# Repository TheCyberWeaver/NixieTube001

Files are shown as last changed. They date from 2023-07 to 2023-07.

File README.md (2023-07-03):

# NixieTube001
# A DIY Project

EL PSY CONGROO

# Including:

python program with GUI

Arduino program

PCB files

3D printing Solidworks files

# Finished Product




# Software





# Contacts

if you do not understand any part of this project, you're welcome to contact thomas.luqiyu@outlook.com
English, German and Chinese are supported (^_^)

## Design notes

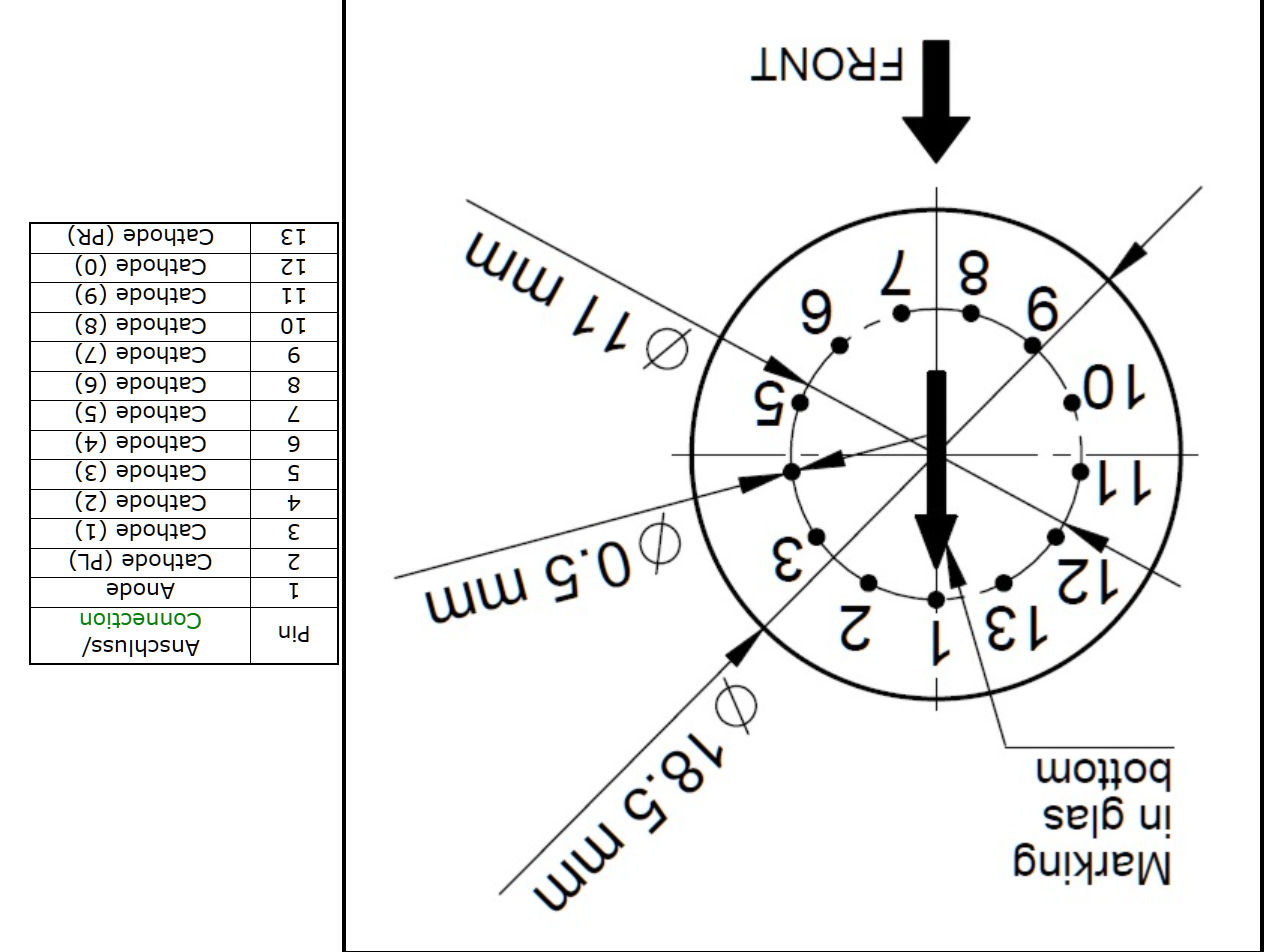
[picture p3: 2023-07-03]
Documents/Screenshot 2023-05-19 155955.png

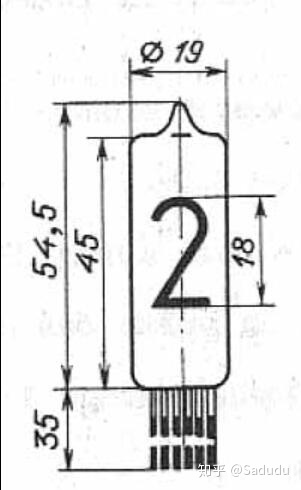
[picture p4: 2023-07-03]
Documents/v2-3904997cc60bc72c79d3f1d0ab6cf48d_1440w.jpg

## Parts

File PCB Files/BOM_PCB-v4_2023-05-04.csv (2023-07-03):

ID | Name | Designator | Footprint | Quantity | Manufacturer Part | Manufacturer | Supplier | Supplier Part | Price | Pins
1 | 22k | R1,R2,R3,R4,R5,R6,R7,R8 | R0603 | 8 |  |  |  |  |  | 2
2 | K155ID1/SN74141 | U14,U2,U3,U5,U6,U9,U10,U12,U8 | DIP16 | 9 |  |  |  |  |  | 16
3 | WIRELESS-BLUETOOTH-HC-05 | 1 | WIRELESS-BLUETOOTH-HC-05 | 1 |  |  |  |  |  | 6
4 | IN-14 | N1,N2,N3,N4,N5,N6,N7,N8 | IN-14 | 8 |  |  |  |  |  | 13
5 | SN74HC595N | U4,U7,U11,U16 | DIP-16_L19.8-W6.5-P2.54-LS7.6-BL | 4 | SN74HC595N | TI(德州仪器) | LCSC | C78711 | 0.037 | 16
6 | DS3231 PI | U15 | DS3231 PI | 1 |  |  |  |  |  | 5
7 | ARDUINO_NANO | U1 | COMM-TH_ARDUINO_NANO | 1 | ARDUINO_NANO | null | LCSC | C9900017879 |  | 30
8 | HDR-M-2.54_1x4 | J1 | HDR-M-2.54_1X4 | 1 |  |  | LCSC | C124378 | 0.007 | 4

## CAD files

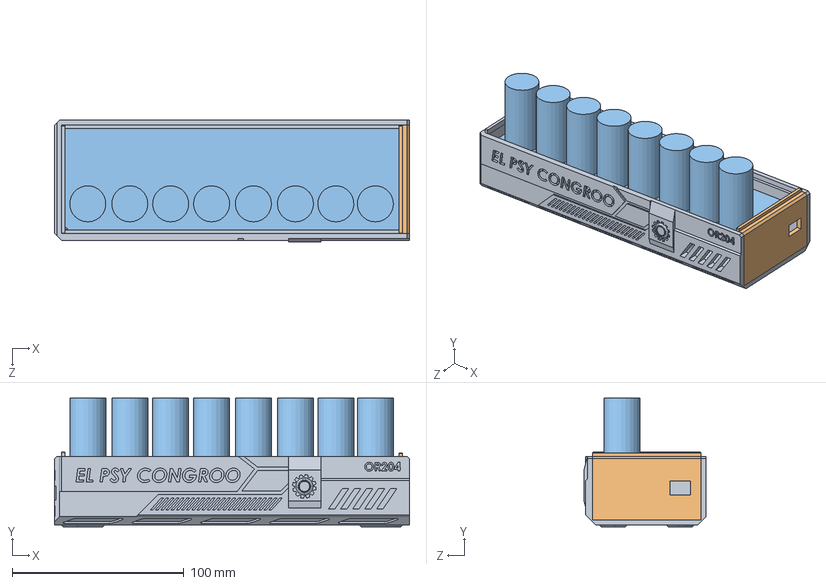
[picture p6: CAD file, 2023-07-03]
Nixie Tube 3D Files/Assem1.SLDASM
206.5 x 74.8 x 71.0 mm
PCB

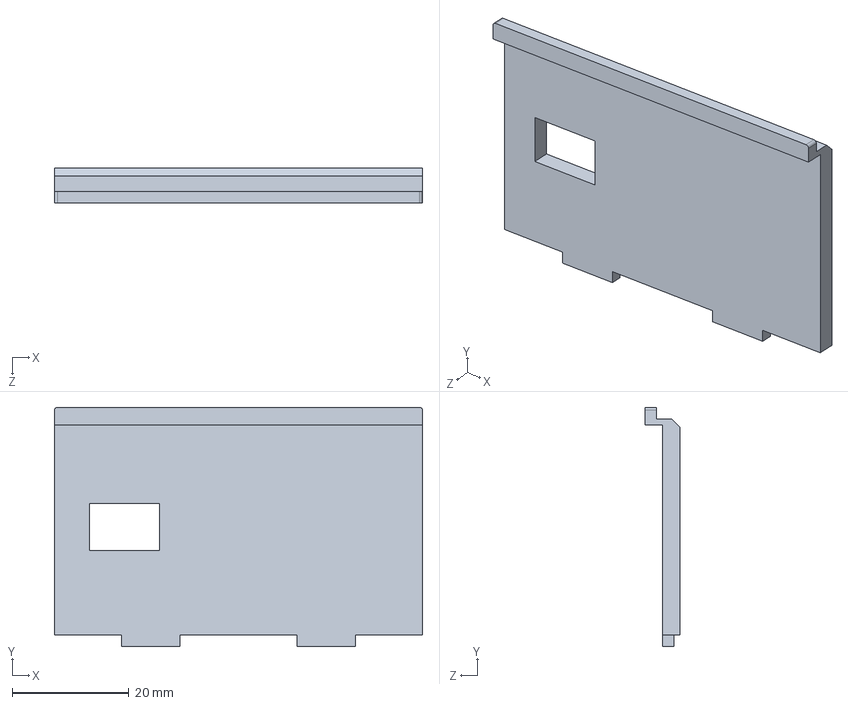
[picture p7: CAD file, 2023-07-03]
Nixie Tube 3D Files/Part2.SLDPRT
63.0 x 41.0 x 6.00 mm

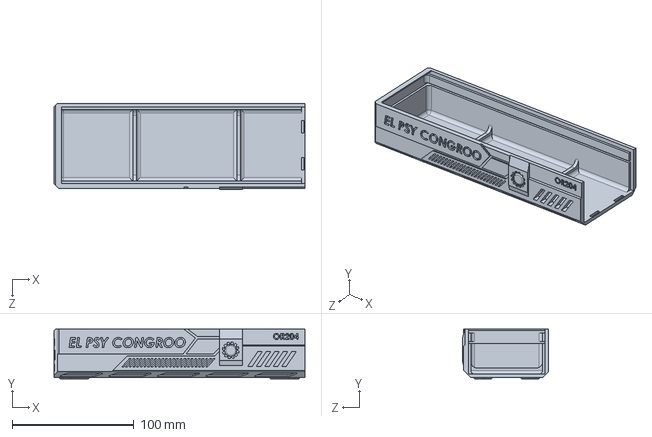
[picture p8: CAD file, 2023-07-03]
Nixie Tube 3D Files/Part1.SLDPRT
206.5 x 41.0 x 71.0 mm

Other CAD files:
Nixie Tube 3D Files/Drawing1.dwg

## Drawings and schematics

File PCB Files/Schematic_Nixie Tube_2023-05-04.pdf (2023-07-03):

A | A
B | B

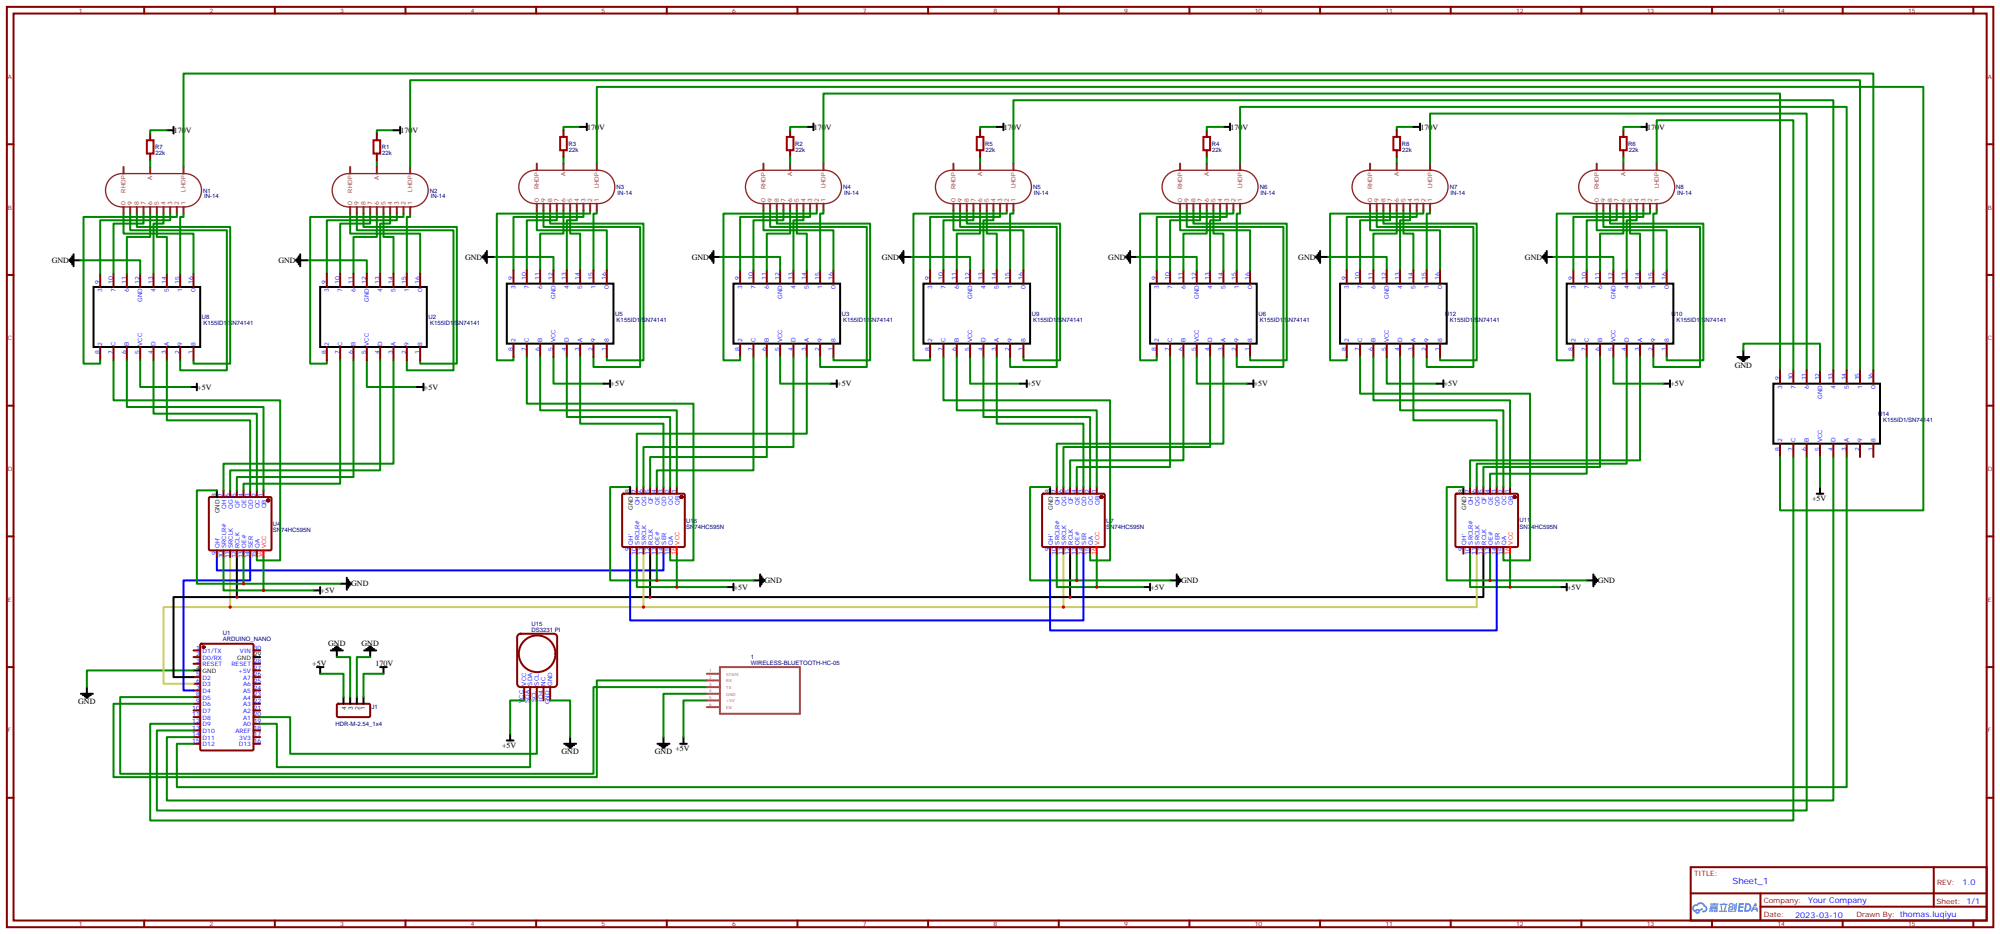
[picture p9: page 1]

GND GND NC IO4 SCL SCL SDA SDA VCC VCC

Drawn By: thomas.luqiyu

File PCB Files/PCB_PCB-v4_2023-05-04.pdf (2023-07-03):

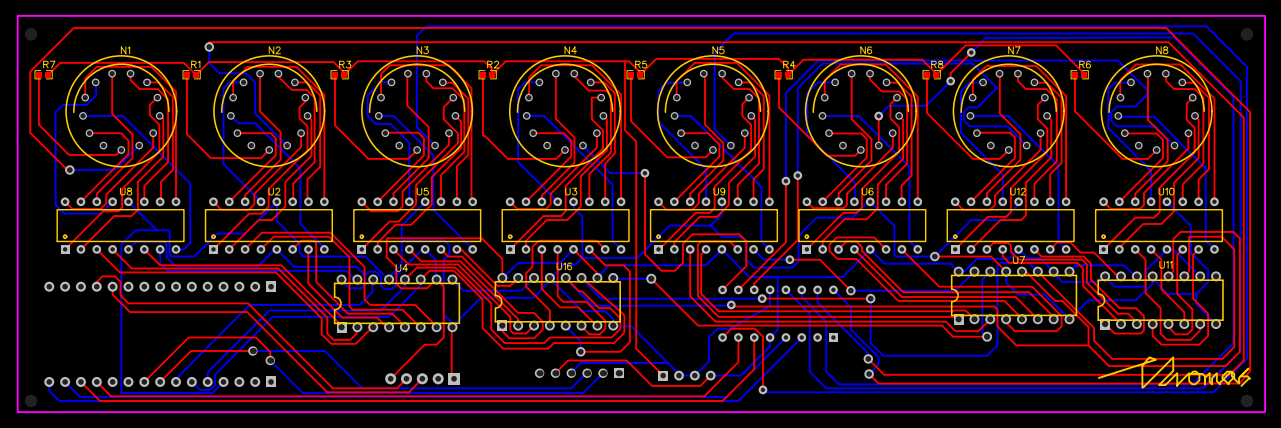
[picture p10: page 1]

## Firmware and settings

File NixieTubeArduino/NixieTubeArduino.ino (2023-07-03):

#include <SoftwareSerial.h>
#include <DS3231.h>
//global

#define dotA 12
#define dotB 10
#define dotC 9
#define dotD 11

#define SR_latchPIN 2
#define SR_clockPIN 3
#define SR_dataPIN 4

bool stopwatchPauseFlag = 1;
bool timerPauseFlag = 1;
uint8_t MODE = 2;
uint8_t timeMODE = 0;
String number = "";
Time stopwatchCurrentTime, timeALLZero, timerCurrentTime, timerResetTime;
uint8_t stopwatchMilli;

uint8_t timeOffset = 3;
int timeOffsetMicro = 603;

//initialization
SoftwareSerial Bluetooth(5, 6);
String inputString;

DS3231 rtc(A0, A1);


//String EXCEPTIONS = "";
bool DecimalPointToPins[9][4]{ { 1, 1, 1, 0 },  //the map between the 4 controlling pins and the LP pin of the nixie tube.
                               { 0, 1, 1, 0 },
                               { 1, 0, 1, 0 },
                               { 0, 0, 1, 0 },
                               { 1, 1, 0, 0 },
                               { 0, 1, 0, 0 },
                               { 1, 0, 0, 0 },
                               { 0, 0, 0, 0 },
                               { 1, 1, 1, 1 } };

uint8_t DigitsToPins[11]{ 0x8, 0x0, 0xC, 0x4, 0xB, 0x3, 0x9, 0x1, 0xA, 0x2, 0xF };  //the map between the output of shift registers and the output of  4 bits decoders. 0xF represents no output!!!



/*
  given a string of 8 digits number/float,
  check if the number/float is valid, if not, try to make it valid.
  If it fails to make it valid, than return false.
*/
bool isNumberValid(String& num) {
  if (num.length() > 8) {
    //EXCEPTIONS = "[Failed]: False digits length";
    return false;
  }
  int countofDecimalPoints = 0;
  for (int i = 0; i < num.length(); ++i) {
    if (num[i] == '.') countofDecimalPoints++;
    if (num[i] == '.' && countofDecimalPoints > 1) num[i] = '0';
    if (num[i] < 48 && num[i] != 46 || num[i] > 57) {
      //EXCEPTIONS = "[Failed]: Found unsupported characters";
      return false;
    }
  }
  if (countofDecimalPoints > 1) {
    //EXCEPTIONS = "[Warning]: change extra decimal points to 0";
  }

  return true;
}
/*
  given the index of the nixie tube,
  light up the nixie tube with a decimal point.
  !!!This function could still show the decimal point while the nixie tube is showing a digit!!!
*/
void showDecimalPoint(uint8_t index = -1) {
  if (index == -1) {
    digitalWrite(dotA, DecimalPointToPins[8][0]);
    digitalWrite(dotB, DecimalPointToPins[8][1]);
    digitalWrite(dotC, DecimalPointToPins[8][2]);
    digitalWrite(dotD, DecimalPointToPins[8][3]);
  } else {
    digitalWrite(dotA, DecimalPointToPins[index][0]);
    digitalWrite(dotB, DecimalPointToPins[index][1]);
    digitalWrite(dotC, DecimalPointToPins[index][2]);
    digitalWrite(dotD, DecimalPointToPins[index][3]);
  }
  return;
}

/*
  given the an array of 0-9 digits, 10 represents no output,
  output all 8 digits to the nixie tubes in the order from left to right.
*/
void NumberArrayToScreen(uint8_t outputDigits[8]) {
  digitalWrite(SR_latchPIN, LOW);
  //using shift register
  for (uint8_t i = 0; i < 4; ++i) {
    int tmp = (DigitsToPins[outputDigits[i * 2]] << 4) + DigitsToPins[outputDigits[i * 2 + 1]];
    shiftOut(SR_dataPIN, SR_clockPIN, MSBFIRST, tmp);
  }
  digitalWrite(SR_latchPIN, HIGH);
  return;
}
/*
  set the timer to the given string
*/
Time stringToTime(String str) {
  Time timer;

  timer.year = 2000 + str.substring(0, 2).toInt();
  timer.mon = str.substring(2, 4).toInt();
  timer.date = str.substring(4, 6).toInt();

  timer.hour = str.substring(6, 8).toInt();
  timer.min = str.substring(8, 10).toInt();
  timer.sec = str.substring(10, 12).toInt();

  return timer;
}

/*
  add time or minue time
*/
void updateCurrentTime(Time& timer, int addnum) {

  timer.sec += addnum;
  if (addnum < 0) {
    if (timer.sec == 255) {  //since time->sec is a uint8_t, it can only represent 0-255. if we minus one when it is zero, it will become 255.
      timer.sec = 59;
      timer.min -= 1;
      if (timer.min == 255) {  //same theory (^-^)
        timer.min = 59;
        timer.hour -= 1;
      }
    }
  }

  if (addnum > 0) {
    timer.min += timer.sec / 60;
    timer.sec = timer.sec % 60;

    timer.hour += timer.min / 60;
    timer.min = timer.min % 60;

    timer.date += timer.hour / 24;
    timer.hour = timer.hour % 24;
  }
}
/*
  given the left number, the index of decimal point and the right number,
  ouput an integer or a float to the nixie tubes.
  Both numbers are right aligned.
*/
void outputNumber(long wholeNumberPart, int decimalPointIndex = -1, long decimalPart = -1) {
  uint8_t outputDigits[8] = { 0 };
  if (decimalPointIndex == -1) {
    //Do not show decimal point
    showDecimalPoint(-1);

    //seperate each digits into an array
    for (int i = 0; i < 8; ++i) {
      if (wholeNumberPart != 0) {
        outputDigits[7 - i] = wholeNumberPart % 10;  //save each digits into the array in the order from left to right
        wholeNumberPart /= 10;
      }
    }
  } else {
    //show decimal point at selected location
    showDecimalPoint(decimalPointIndex);

    outputDigits[decimalPointIndex] = 10;
    for (int i = 0; i < 8; ++i) {
      if (wholeNumberPart != 0) {
        outputDigits[decimalPointIndex - i - 1] = wholeNumberPart % 10;  //save each digits into the array in the order from left to right
        wholeNumberPart /= 10;
      }
      if (decimalPart != 0) {
        outputDigits[7 - i] = decimalPart % 10;  //save each digits into the array in the order from left to right
        decimalPart /= 10;
      }
    }
  }
  NumberArrayToScreen(outputDigits);
  return;
}

/*
  given 3 two digits number, 
  ouput them to the nixie tubes with a space between each two digits number.
*/
void outputTime(uint8_t aa, uint8_t bb, uint8_t cc) {
  aa %= 100;
  bb %= 100;
  cc %= 100;
  showDecimalPoint(-1);
  uint8_t outputDigits[8]{ aa / 10, aa % 10, 10, bb / 10, bb % 10, 10, cc / 10, cc % 10 };
  NumberArrayToScreen(outputDigits);
  return;
}

void chaos(uint8_t rest) {
  outputNumber(12345678);
  delay(rest);
  outputNumber(23456781);
  delay(rest);
  outputNumber(34567812);
  delay(rest);
  outputNumber(45678123);
  delay(rest);
  outputNumber(56781234);
  delay(rest);
  outputNumber(67812345);
  delay(rest);
  outputNumber(78123456);
  delay(rest);
  outputNumber(81234567);
  delay(rest);
}

/*
  if the bluetooth module recieve any string, it temporarily stores it in input_string.
  If no data is recieved in 2 miliseconds, the later data will be considered as a new input string.
*/
void getInputFromBluetooth() {
  String temp_string = "";                  // store temp input data
  while (Bluetooth.available()) {           // if there is data that can be read，then loop
    temp_string += (char)Bluetooth.read();  // join the new data into temp string
    delay(2);
  }
  inputString = temp_string;  // save to global variable.
}

/*
  check if a string has a decimal point. 
  If there is, return the index of that decimal point.
  If not, return -1.
*/
int isFloat(String str) {
  for (int i = 0; i < str.length(); i++) {
    if (str[i] == '.') return i;
  }
  return -1;
}

/*
  Since running the programm also cost some time, 
  we need to subtract a certain amount of time when we need to delay one second.

  real delay time = 1000ms - timeOffset (ms) + timeOffsetMicro (us)
*/
void delayOneSecondWithOffset() {
  if (millis() % 10000 <= 1000) {
    delay(200 - timeOffset);
    delayMicroseconds(timeOffsetMicro);
    chaos(100);
  } else
    delay(1000 - timeOffset);
  delayMicroseconds(timeOffsetMicro);
}

const String INSTR_MODE = "[MODE]";
const String INSTR_NUMBER = "[NUMBER]";
const String INSTR_SYNCTIME = "[SYNCTIME]";
const String INSTR_TIMEMODE = "[TIMEMODE]";
const String INSTR_STOPWATCH = "[STOPWATCH]";
const String INSTR_TIMER = "[TIMER]";

const uint8_t INSTR_MODE_LENGTH = INSTR_MODE.length();
const uint8_t INSTR_NUMBER_LENGTH = INSTR_NUMBER.length();
const uint8_t INSTR_SYNCTIME_LENGTH = INSTR_SYNCTIME.length();
const uint8_t INSTR_TIMEMODE_LENGTH = INSTR_TIMEMODE.length();
const uint8_t INSTR_STOPWATCH_LENGTH = INSTR_STOPWATCH.length();
const uint8_t INSTR_TIMER_LENGTH = INSTR_TIMER.length();

void setup() {


  timerCurrentTime.hour = 1;  //default stopWatch time

  rtc.begin();  //rtc clock begin

  Serial.begin(9600);
  Bluetooth.begin(9600);

  pinMode(SR_latchPIN, OUTPUT);
  pinMode(SR_clockPIN, OUTPUT);
  pinMode(SR_dataPIN, OUTPUT);

  pinMode(dotA, OUTPUT);
  pinMode(dotB, OUTPUT);
  pinMode(dotC, OUTPUT);
  pinMode(dotD, OUTPUT);
}

void loop() {
  unsigned long start=micros();
  getInputFromBluetooth();

  //if (inputString != "") Serial.println("[Info]: Input string:" + String(inputString));

  //Change Mode
  if (inputString.substring(0, INSTR_MODE_LENGTH) == INSTR_MODE) {
    MODE = inputString.substring(INSTR_MODE_LENGTH).toInt();

    //Bluetooth.println("Changed to MODE" + String(MODE));  //debug output
    //Serial.println("Changed to MODE" + String(MODE));     //debug output
  }
  //change the number of mode 1
  else if (inputString.substring(0, INSTR_NUMBER_LENGTH) == INSTR_NUMBER) {
    number = inputString.substring(INSTR_NUMBER_LENGTH);
    //Bluetooth.println("Changed number to: " + number);  //debug output
  }


  else if (inputString.substring(0, INSTR_SYNCTIME_LENGTH) == INSTR_SYNCTIME) {
    String parameter = inputString.substring(INSTR_SYNCTIME_LENGTH);
    Time timeNeedToBeSet = stringToTime(parameter);

    rtc.setDate(timeNeedToBeSet.date, timeNeedToBeSet.mon, timeNeedToBeSet.year);  //day,month,year
    rtc.setTime(timeNeedToBeSet.hour, timeNeedToBeSet.min, timeNeedToBeSet.sec);

    //Bluetooth.println("set current time: " + inputString.substring(INSTR_SYNCTIME_LENGTH));  //debug output
  }

  //change the time mode of mode 2
  else if (inputString.substring(0, INSTR_TIMEMODE_LENGTH) == INSTR_TIMEMODE) {
    timeMODE = inputString.substring(INSTR_TIMEMODE_LENGTH).toInt();
    //Bluetooth.println("change time mode to" + inputString.substring(INSTR_TIMEMODE_LENGTH));  //debug output
  }

  //configuration of mode 3
  else if (inputString.substring(0, INSTR_STOPWATCH_LENGTH) == INSTR_STOPWATCH) {
    if (inputString.substring(INSTR_STOPWATCH_LENGTH) == "RESET") {
      stopwatchCurrentTime = timeALLZero;
      stopwatchPauseFlag = 1;
      stopwatchMilli=0;
      //Bluetooth.println("RESET TIME TO 0");  //debug output
    } else if (inputString.substring(INSTR_STOPWATCH_LENGTH) == "PAUSE") {
      stopwatchPauseFlag = 1;
      //Bluetooth.println("Paused");  //debug output
    } else if (inputString.substring(INSTR_STOPWATCH_LENGTH) == "CONTINUE") {
      stopwatchPauseFlag = 0;
      //Bluetooth.println("Continue");  //debug output
    }
  }
  //configuration of mode 4
  else if (inputString.substring(0, INSTR_TIMER_LENGTH) == INSTR_TIMER) {
    if (inputString.substring(INSTR_TIMER_LENGTH) == "CONTINUE") {
      timerPauseFlag = 0;
      //Bluetooth.println("Continue");  //debug output
    } else if (inputString.substring(INSTR_TIMER_LENGTH) == "PAUSE") {
      timerPauseFlag = 1;
      //Bluetooth.println("Paused");  //debug output
    } else if (inputString.substring(INSTR_TIMER_LENGTH) == "RESET") {
      timerPauseFlag = 1;
      timerCurrentTime = timerResetTime;
      //Bluetooth.println("reset");  //debug output
    } else {
      String parameter = inputString.substring(INSTR_TIMER_LENGTH);

      timerResetTime = stringToTime(parameter);
      timerCurrentTime = timerResetTime;

      timerPauseFlag = 1;
      //Bluetooth.println("set initial time: " + inputString.substring(INSTR_TIMER_LENGTH));  //debug output
    }
  }



  switch (MODE) {
    //Reserved
    //constantly showing one number
    case 1:
      {
        //Serial.println("[info]: MODE 1");
        int index = isFloat(number);
        if (index != -1) {
          outputNumber(number.substring(0, index).toInt(), index, number.substring(index + 1).toInt());
        } else {
          outputNumber(number.toInt());
        }
        delayOneSecondWithOffset();
        break;
      }
    //showing time
    case 2:
      {
        
        Time now = rtc.getTime();
        //Serial.println("[info]: MODE 2");

        if (timeMODE == 0) {
          outputTime(now.hour, now.min, now.sec);
        }
        if (timeMODE == 1) {
          outputTime(now.hour % 12, now.min, now.sec);
        }
        if (timeMODE == 2) {
          outputTime(now.year%100, now.mon, now.date);
        }
        //unsigned long end=micros();

        //Serial.println(end-start);
        delayOneSecondWithOffset();
        break;
      }
    //timer
    case 3:
      {
        //Serial.println("[info]: MODE 3");
        outputTime(stopwatchCurrentTime.min, stopwatchCurrentTime.sec, stopwatchMilli);
        if (stopwatchPauseFlag == 0 && stopwatchMilli==99) {
          updateCurrentTime(stopwatchCurrentTime, 1);
        }
        if (stopwatchPauseFlag == 0) {
          stopwatchMilli+=1;
          stopwatchMilli%=100;
        }
        //unsigned long end=micros();

        //Serial.println(end-start);

        delay(9);
        delayMicroseconds(136);
        break;
      }
    //stopwatch
    case 4:
      {
        //Serial.println("[info]: MODE 4");
        if (timerCurrentTime.hour == 0 && timerCurrentTime.min == 0 && timerCurrentTime.sec == 0) {
          timerPauseFlag = 1;
        }
        outputTime(timerCurrentTime.hour, timerCurrentTime.min, timerCurrentTime.sec);
        if (timerPauseFlag == 0) {
          updateCurrentTime(timerCurrentTime, -1);
        }

        delayOneSecondWithOffset();
        break;
      }
    //Undefined
    default:
      {
        //Serial.println("[info]: MODE UNDEFINED");
        outputNumber(99999999);

        delayOneSecondWithOffset();
        break;
      }
  }
}

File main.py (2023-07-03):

from threading import Thread
from time import sleep, ctime
# IMPORT PACKAGES AND MODULES
# ///////////////////////////////////////////////////////////////
from gui.uis.windows.main_window.functions_main_window import *
import sys
import os

import time
from Bluetest import *

import serial
import serial.tools.list_ports

# IMPORT QT CORE
# ///////////////////////////////////////////////////////////////
from qt_core import *

# IMPORT SETTINGS
# ///////////////////////////////////////////////////////////////
from gui.core.json_settings import Settings

# IMPORT PY ONE DARK WINDOWS
# ///////////////////////////////////////////////////////////////
# MAIN WINDOW
from gui.uis.windows.main_window import *

# IMPORT PY ONE DARK WIDGETS
# ///////////////////////////////////////////////////////////////
from gui.widgets import *

# ADJUST QT FONT DPI FOR HIGHT SCALE AN 4K MONITOR
# ///////////////////////////////////////////////////////////////
os.environ["QT_FONT_DPI"] = "96"
os.environ["QT_SCALE_FACTOR"] = "1.5"
# IF IS 4K MONITOR ENABLE 'os.environ["QT_SCALE_FACTOR"] = "2"'
# IF IS 2K MONITOR ENABLE 'os.environ["QT_SCALE_FACTOR"] = "1.5"'

# MAIN WINDOW
# ///////////////////////////////////////////////////////////////
class MainWindow(QMainWindow):
    def __init__(self):
        super().__init__()

        # SETUP MAIN WINDOw
        # Load widgets from "gui\uis\main_window\ui_main.py"
        # ///////////////////////////////////////////////////////////////
        self.ui = UI_MainWindow()
        self.ui.setup_ui(self)

        # LOAD SETTINGS
        # ///////////////////////////////////////////////////////////////
        settings = Settings()
        self.settings = settings.items

        self.setWindowIcon(QIcon(self.settings["icon"]))

        self.Port = self.settings["port"]
        self.BluetoothSerial=serial.Serial()
        # SETUP MAIN WINDOW
        # ///////////////////////////////////////////////////////////////
        self.hide_grips = True # Show/Hide resize grips
        SetupMainWindow.setup_gui(self)
        MainFunctions.set_page(self, self.ui.load_pages.page_1)
        # SHOW MAIN WINDOW
        # ///////////////////////////////////////////////////////////////
        self.show()

        self.uiInitiation()

        self.portList=[]


    def uiInitiation(self):
        self.push_button_Open.clicked.connect(lambda: self.flipPort())
        self.push_button_Show.clicked.connect(lambda: self.send("[NUMBER]"+self.line_edit.text()))
        self.push_button_EL.clicked.connect(lambda: self.send("[NUMBER]0.337187"))

        self.push_button_SyncTime.clicked.connect(lambda: self.syncTime())

        self.push_button_stopwatch_start.clicked.connect(lambda: self.stopwatchStart())
        self.push_button_stopwatch_reset.clicked.connect(lambda: self.stopwatchReset())

        self.push_button_timer_start.clicked.connect(lambda: self.timerStart())
        self.push_button_timer_reset.clicked.connect(lambda: self.timerReset())

        self.toggle_button.stateChanged.connect(lambda: self.changeTimeMode())

    def changeTimeMode(self):
        if not self.toggle_button.isChecked():
            self.send("[TIMEMODE]0")
        elif self.toggle_button.isChecked():
            self.send("[TIMEMODE]2")
    def timerStart(self):
        if self.push_button_timer_start.text() == "Start":
            try:
                hour=str(int(self.line_edit_Hour.text())%24).rjust(2,"0")
            except:
                hour="00"

            try:
                minute=str(int(self.line_edit_Minute.text())%60).rjust(2,"0")
            except:
                minute="00"

            try:
                second=str(int(self.line_edit_Second.text())%60).rjust(2,"0")
            except:
                second="00"

            self.send("[TIMER]"+"000000"+hour+minute+second)
            sleep(1)
            self.send("[TIMER]CONTINUE")
            self.push_button_timer_start.setText("Pause")

        elif self.push_button_timer_start.text() == "Continue":
            self.push_button_timer_start.setText("Pause")
            self.send("[TIMER]CONTINUE")

        elif self.push_button_timer_start.text() == "Pause":
            self.push_button_timer_start.setText("Continue")
            self.send("[TIMER]PAUSE")


    def timerReset(self):
        self.send("[TIMER]RESET")
        self.push_button_timer_start.setText("Start")

    def stopwatchStart(self):
        if self.push_button_stopwatch_start.text()=="Start" or self.push_button_stopwatch_start.text()=="Continue":
            self.send("[STOPWATCH]CONTINUE")
            self.push_button_stopwatch_start.setText("Pause")
        elif self.push_button_stopwatch_start.text()=="Pause":
            self.send("[STOPWATCH]PAUSE")
            self.push_button_stopwatch_start.setText("Continue")

    def stopwatchReset(self):
        self.send("[STOPWATCH]RESET")
        self.push_button_stopwatch_start.setText("Start")

    def send(self,str):
        try:
            self.BluetoothSerial.write(str.encode('utf-8'))
            print("[NTC][Info]: send command: " + str)
            self.showState("successfully opened Port " + self.BluetoothSerial.name, "green")
        except:
            print("[NTC][Failed]: failed sending command: "+str)
            self.showState("Connection failed","red")


    def syncTime(self):
        t = time.localtime()
        tString=str(t.tm_year)[-2:]+ str(t.tm_mon).rjust(2, '0')+ str(t.tm_mday).rjust(2, '0')+str(t.tm_hour).rjust(2, '0')+ str(t.tm_min).rjust(2, '0')+ str(t.tm_sec).rjust(2, '0')

        self.send("[SYNCTIME]"+tString)

    def flipPort(self):
        if self.push_button_Open.text()=="Connect":
            self.portList = list(serial.tools.list_ports.comports())

            foundNixie=0
            if len(self.portList) <= 0:
                print("[NTC][Failed]:No Port Available")
                self.showState("No Port Available","red")

            else:
                for comport in self.portList:
                    if(list(comport)[0])==self.Port:
                        foundNixie=1
                if foundNixie==0:
                    self.showState("Cannot Find Nixie Tube", "red")
                    print("[NTC][Failed]:Cannot Find Nixie Tube")
                else:
                    self.showState("Found Port, Connecting...", "yellow")
                    print("[NTC][Info]:Found Port, Connecting...")

            try:
                self.BluetoothSerial = serial.Serial(self.Port, 9600)
                if self.BluetoothSerial.isOpen():  # 判断串口是否成功打开
                    print("[NTC][Info]:Open Port Successful")
                    self.showState("successfully opened Port "+self.BluetoothSerial.name,"green")
                    self.push_button_Open.setText("Disconnect")
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
